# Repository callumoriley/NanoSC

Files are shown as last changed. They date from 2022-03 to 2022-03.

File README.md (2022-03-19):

# NanoSC
A brushless DC motor driver/speed controller based around the Arduino Nano

Note: there are 3 firmware versions using different timing schemes. There is BLDC_driver, which just uses delays and millis() for the timing events, and there are BLDC_driver_timer and BLDC_driver_timer_2 that use the ATMega328P's hardware timers and interrupts for the time events. BLDC_driver_timer uses only timer interrupts for its timing events and BLDC_driver_timer_2 uses timer interrupts for the commutation loop but micros() for the PWM signal generation.

Paradoxically, BLDC_driver seems to be the best at driving motors right now, as using the software timed events has a wider range of commutation frequencies that it can work at, but the timer versions were good opportunities to learn about AVR hardware timers.

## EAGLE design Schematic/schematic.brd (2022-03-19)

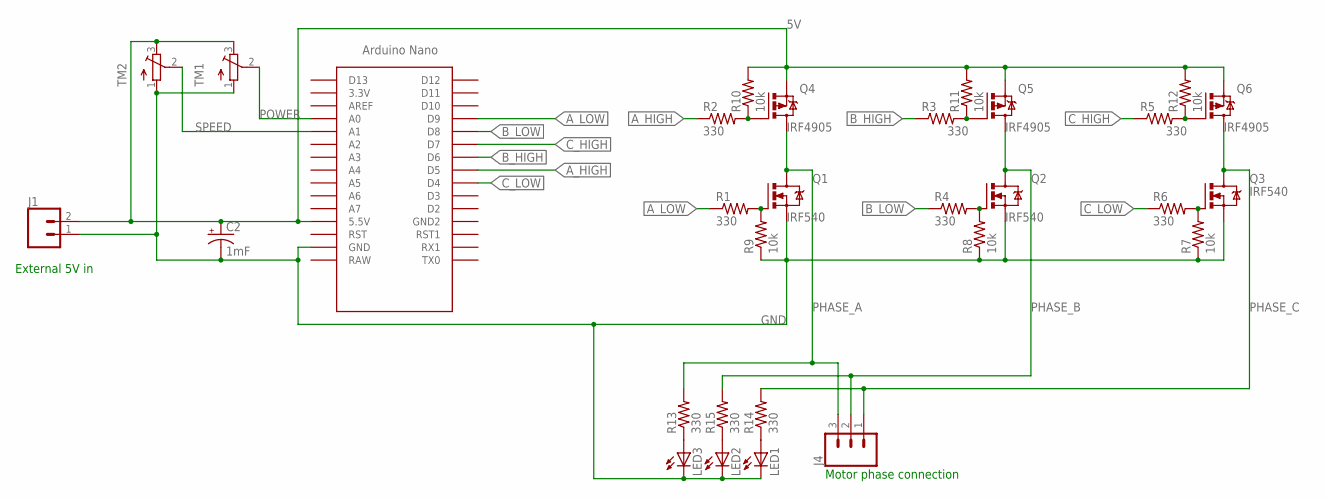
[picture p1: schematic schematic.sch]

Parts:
C2: 1mF; CPOL-RADIAL-5MM-10MM
J1: CONN_025MM; SCREWTERMINAL-5MM-2
J4: CONN_03-SCREW-5MM; SCREWTERMINAL-5MM-3
LED1, LED2, LED3: LED5MM
Q1, Q2, Q3: IRF540; TO220BV
Q4, Q5, Q6: IRF4905; TO220BH
R1, R2, R3, R4, R5, R6, R13, R14, R15: 330; 0204/5
R7, R8, R9, R10, R11, R12: 10k; 0204/5
TM1, TM2: TRIMPOT3386; TRIM-3386
U$1: NANO

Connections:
5V: C2.+, J1.2, Q4.S, Q5.S, Q6.S, R10.2, R11.2, R12.2, TM1.3 (E), TM2.3 (E), U$1.5V (5.5V)
A_HIGH: R2.1, U$1.D5
A_LOW: R1.1, U$1.D9
B_HIGH: R3.1, U$1.D6
B_LOW: R4.1, U$1.D8
C_HIGH: R5.1, U$1.D7
C_LOW: R6.1, U$1.D4
GND: C2.-, J1.1, LED1.K (C), LED2.K (C), LED3.K (C), Q1.S, Q2.S, Q3.S, R7.1, R8.1, R9.1, TM1.1 (A), TM2.1 (A), U$1.GND
unnamed: Q1.G, R1.2, R9.2
unnamed: Q4.G, R2.2, R10.1
unnamed: Q5.G, R3.2, R11.1
unnamed: Q2.G, R4.2, R8.2
unnamed: Q6.G, R5.2, R12.1
unnamed: Q3.G, R6.2, R7.2
unnamed: LED1.A, R14.1
unnamed: LED2.A, R15.1
unnamed: LED3.A, R13.1
PHASE_A: J4.3, Q1.D, Q4.D, R13.2
PHASE_B: J4.2, Q2.D, Q5.D, R15.2
PHASE_C: J4.1, Q3.D, Q6.D, R14.2
POWER: TM1.2 (S), U$1.A0
SPEED: TM2.2 (S), U$1.A1

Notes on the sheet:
External 5V in
Motor phase connection

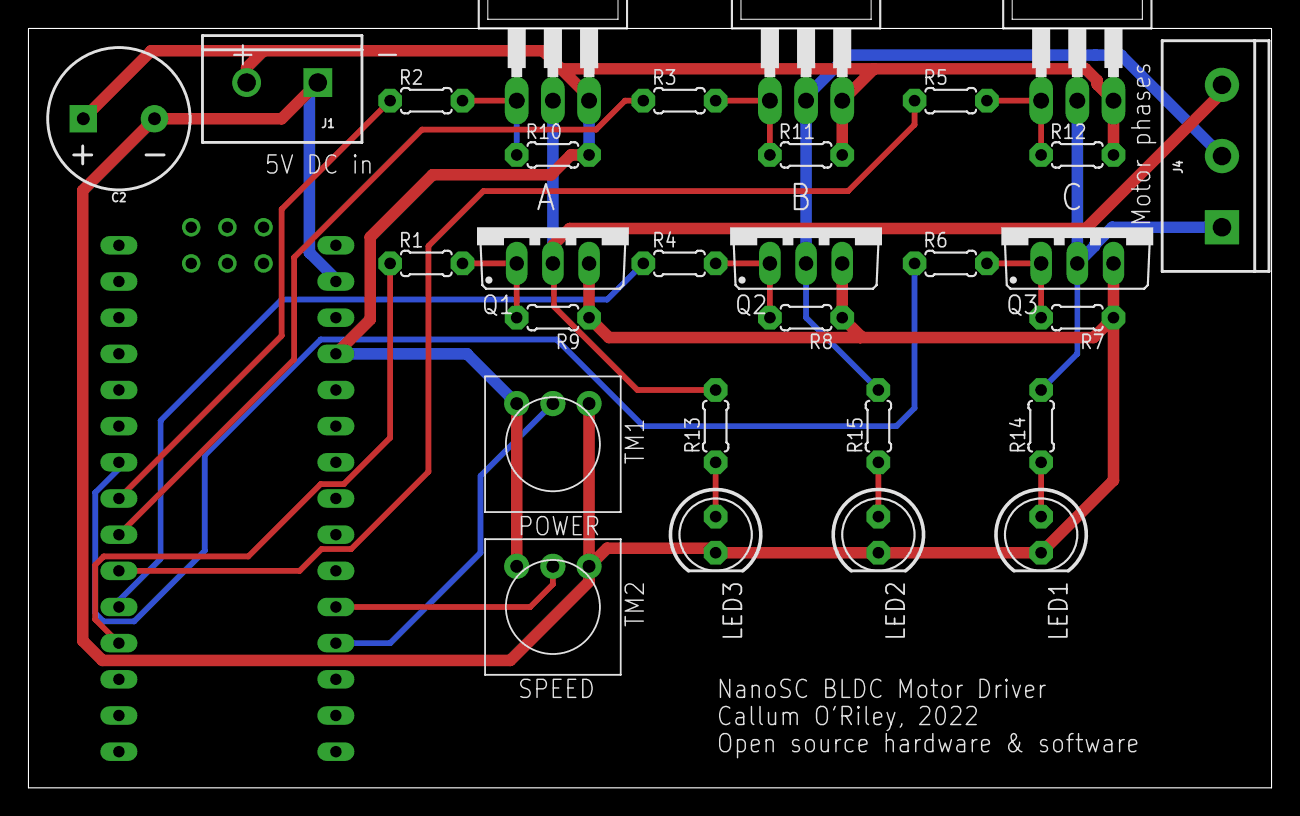
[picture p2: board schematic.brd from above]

Board: 2 copper layers, 87.3 x 53.3 mm, 30 parts (0 on the bottom side), 22 nets.

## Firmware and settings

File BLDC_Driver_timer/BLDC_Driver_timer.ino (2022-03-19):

/*
 * Step: 1 2 3 4 5 6
 * High: A B B C C A
 * Low:  C C A A B B
 * 
 * Used this video as a reference for implementing timers: https://www.youtube.com/watch?v=IdL0_ZJ7V2s
 * Also referenced the datasheet: https://ww1.microchip.com/downloads/en/DeviceDoc/Atmel-7810-Automotive-Microcontrollers-ATmega328P_Datasheet.pdf
 */

#define LOW_A 9
#define LOW_B 8
#define LOW_C 4

#define HIGH_A 5
#define HIGH_B 6
#define HIGH_C 7

// MIN_FREQ, MAX_FREQ, and PULSE_FREQ in Hz
// NOTE: With the current timer configuration, 100 Hz seems like a hard maximum for the commutation frequency
#define MIN_FREQ 1
#define MAX_FREQ 100
#define PULSE_FREQ 1000UL

#define F_CLOCK 16000000UL
#define PRSC0 64
#define PRSC1 256

const int highPins[] = {HIGH_A, HIGH_B, HIGH_B, HIGH_C, HIGH_C, HIGH_A};
const int lowPins[] = {LOW_C, LOW_C, LOW_A, LOW_A, LOW_B, LOW_B};

int commStep = 0; // 0 to 5 corresponding with the steps in the comment above
int targetFreq = MIN_FREQ; // target commutation frequency
int dutyCycle = 50;

void setup() {
  // low side pins
  pinMode(LOW_A, OUTPUT); // A phase
  pinMode(LOW_B, OUTPUT); // B phase
  pinMode(LOW_C, OUTPUT); // C phase

  // high side pins
  pinMode(HIGH_A, OUTPUT); // A phase
  pinMode(HIGH_B, OUTPUT); // B phase
  pinMode(HIGH_C, OUTPUT); // C phase

  // Timer 0 configuration
  TCCR0A = 0;
  TCCR0B = 0;
  OCR0A = F_CLOCK/(PRSC0*PULSE_FREQ);
  OCR0B = OCR0A-1-(OCR0A-1)*dutyCycle/100;
  TCNT0 = 0;
  TCCR0B |= (1 << CS01) | (1 << CS00) | (1 << WGM02); // prescaler 64, CTC mode
  TIMSK0 |= (1 << OCIE0A) | (1 << OCIE0B); // enable compare match interrupt

  // Timer 1 configuration
  TCCR1A = 0;
  TCCR1B = 0;
  TCNT1 = 65536 - F_CLOCK/(PRSC1*targetFreq);
  TCCR1B |= (1 << CS12); // prescaler 256
  TIMSK1 |= (1 << TOIE1); // enable timer overflow interrupt
  
  setPinsToDefault();
}
ISR(TIMER0_COMPA_vect) { // set pins low when timer 0 hits OCR0A
  OCR0B = OCR0A-1-(OCR0A-1)*dutyCycle/100;
  setPinsToDefault();
}
ISR(TIMER0_COMPB_vect) { // set pins high when timer 0 hits OCR0B
  digitalWrite(highPins[commStep], LOW);
  digitalWrite(lowPins[commStep], HIGH);
}
ISR(TIMER1_OVF_vect) { // step commutation
  if (++commStep > 5) {
    commStep = 0;
  }
  TCNT1 = 65536 - F_CLOCK/(PRSC1*targetFreq);
}
void loop() {
  dutyCycle = map(analogRead(A0), 0, 1023, 0, 100); // the time that the MOSFETs will be conducting
  targetFreq = map(analogRead(A1), 0, 1023, MIN_FREQ, MAX_FREQ); // the frequency that the commutation switches (in Hz)
}
void setPinsToDefault(void) {
  digitalWrite(LOW_A, LOW);
  digitalWrite(LOW_B, LOW);
  digitalWrite(LOW_C, LOW);

  digitalWrite(HIGH_A, HIGH);
  digitalWrite(HIGH_B, HIGH);
  digitalWrite(HIGH_C, HIGH);
}

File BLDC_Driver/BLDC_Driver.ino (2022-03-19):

/*
 * Step: 1 2 3 4 5 6
 * High: A B B C C A
 * Low:  C C A A B B
 */

#define LOW_A 9
#define LOW_B 8
#define LOW_C 4

#define HIGH_A 5
#define HIGH_B 6
#define HIGH_C 7

// PERIOD in microseconds (1000 us = 1 ms = 1khz signal)
#define PERIOD 1000
// MAX_DURATION in milliseconds
#define MAX_DURATION 100

void setup() {
  // low side pins
  pinMode(LOW_A, OUTPUT); // A phase
  pinMode(LOW_B, OUTPUT); // B phase
  pinMode(LOW_C, OUTPUT); // C phase

  // high side pins
  pinMode(HIGH_A, OUTPUT); // A phase
  pinMode(HIGH_B, OUTPUT); // B phase
  pinMode(HIGH_C, OUTPUT); // C phase

  Serial.begin(9600);
}

void loop() {
  int timeHigh = map(analogRead(A0), 0, 1023, 0, PERIOD); // the time that the MOSFETs will be conducting
  int duration = map(analogRead(A1), 0, 1023, 0, MAX_DURATION); // the duration that the signal is running for (in milliseconds)

  Serial.print(timeHigh);
  Serial.print(' ');
  Serial.println(duration);
  
  setState(HIGH_A, LOW_C, timeHigh, PERIOD, duration); // motor commutation loop
  setState(HIGH_B, LOW_C, timeHigh, PERIOD, duration);
  setState(HIGH_B, LOW_A, timeHigh, PERIOD, duration);
  setState(HIGH_C, LOW_A, timeHigh, PERIOD, duration);
  setState(HIGH_C, LOW_B, timeHigh, PERIOD, duration);
  setState(HIGH_A, LOW_B, timeHigh, PERIOD, duration);
}
void setState(int highPin, int lowPin, int condTime, int period, int duration) { // forgive me, I don't know how to use timer interrupts on an AVR
  unsigned long startTime = millis();
  setPinsToDefault();
  int lowTime = period - condTime;

  while (millis() < (startTime + duration)) {
    digitalWrite(highPin, LOW);
    digitalWrite(lowPin, HIGH);
    delayMicroseconds(condTime); // please forgive me
    digitalWrite(highPin, HIGH);
    digitalWrite(lowPin, LOW);
    delayMicroseconds(lowTime); // I promise I know how to use them on the 8051, just not on this chip. I promise I will learn someday
  }

  setPinsToDefault();
}
void setPinsToDefault(void) {
  digitalWrite(LOW_A, LOW);
  digitalWrite(LOW_B, LOW);
  digitalWrite(LOW_C, LOW);

  digitalWrite(HIGH_A, HIGH);
  digitalWrite(HIGH_B, HIGH);
  digitalWrite(HIGH_C, HIGH);
}

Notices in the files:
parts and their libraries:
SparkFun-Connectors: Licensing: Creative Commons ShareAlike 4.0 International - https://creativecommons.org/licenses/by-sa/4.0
